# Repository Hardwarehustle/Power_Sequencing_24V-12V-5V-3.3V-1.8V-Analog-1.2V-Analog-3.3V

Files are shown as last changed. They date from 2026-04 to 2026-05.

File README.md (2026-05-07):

# Power Sequencing Design — Multi-Rail DC Power Distribution Board

## Project Overview

This project presents a **complete multi-rail power sequencing board** that converts **250V AC mains** down to a cascaded hierarchy of DC voltage rails — from 24V down to 1.2V — for powering mixed-signal embedded systems. The board supports **SoC/MCU cores, analog front-ends, relay/driver circuits**, and precision ADC/DAC references, all with controlled power-up sequencing via MCU GPIO enable pins.

The design covers:
- Full **schematic capture** in EasyEDA
- **PCB layout** with proper power and ground plane separation
- **Component selection** rationale with IC datasheets
- **MCU-controlled enable sequencing** via GPIO + P-MOSFET
- **Verification & Validation plan** (LTSpice simulation + physical testing)

---

## Project Visuals

### Schematic
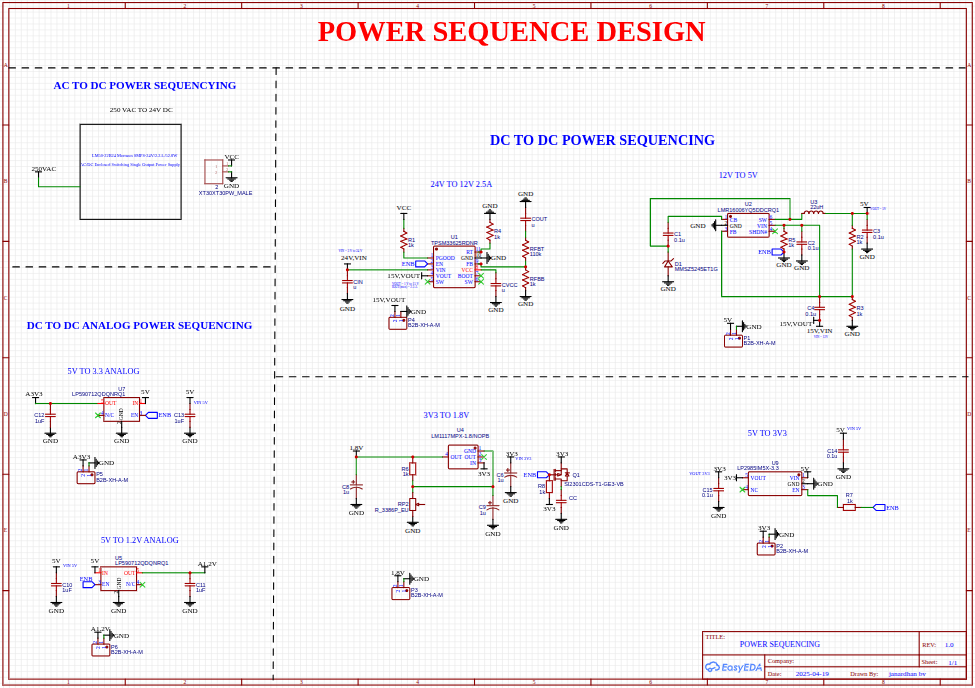
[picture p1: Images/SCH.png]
Schematic


### PCB Layout
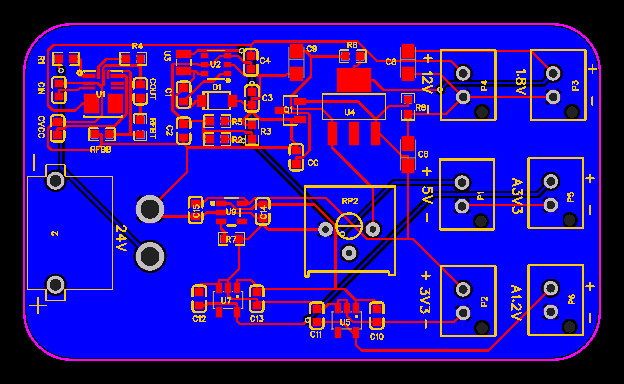
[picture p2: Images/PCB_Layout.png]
PCB Layout


### 3D Board Top View
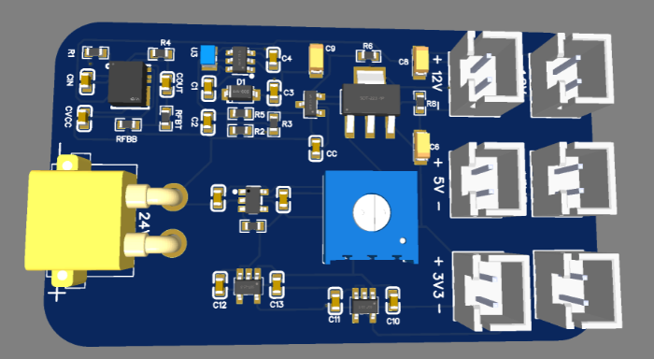
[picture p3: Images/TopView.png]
3D Top View


### 3D Board Bottom View
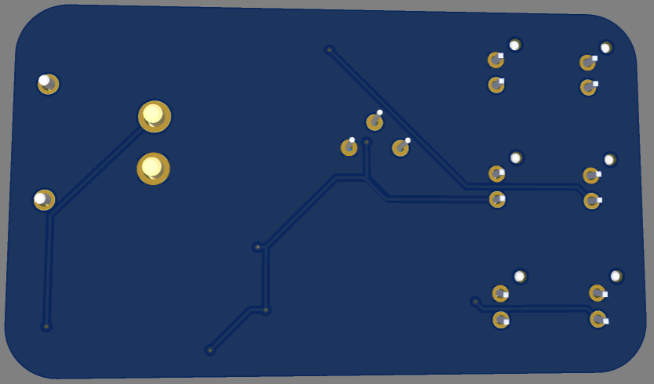
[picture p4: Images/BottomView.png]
3D Bottom View


---

## Power Architecture

The board implements a **top-down cascaded power tree**:

```
250V AC
   └─► 24V DC  (AC-DC SMPS — Mean Well LRS-35-24)
           ├─► 12V DC  (Buck Converter — LM2675-12)
           └─► 5V DC   (Buck Converter — LM7805 / LM2675-5.0)
                   ├─► 3.3V Digital   (LDO — TLV1117-33)
                   ├─► 1.8V Digital   (LDO — LM1117MPX-1.8)
                   ├─► Analog 1.2V    (Precision LDO — TPS7A02-1.2)
                   └─► Analog 3.3V    (Low-Noise LDO — TPS7A4700)
```

**Power-up sequence:**  
`24V → 12V → 5V → 3.3V → 1.8V → Analog 1.2V → Analog 3.3V`

---

## Load Requirements

| Voltage Rail | Load Current | Purpose |
|:---:|:---:|:---|
| 12V | 300 mA | Relay / Driver Circuits |
| 5V | 5 mA | MCU Supply, LDO Inputs |
| 3.3V (Digital) | 10 mA | MCU I/O, Comm. Interfaces |
| 1.8V | 100 mA | SoC / MCU Core Voltage |
| Analog 1.2V | 150 mA | ADC/DAC References |
| Analog 3.3V | 100 mA | Analog Sensors / Op-Amps |

---

## Component Selection

| Voltage Domain | Load | Type | IC | Why Selected |
|:---|:---:|:---:|:---|:---|
| 24V (AC-DC) | 2.2A | SMPS | Mean Well LRS-35-24 | Reliable, compact, 35W rated |
| 12V | 300 mA | Buck Reg | LM2675-12 | High-efficiency, 1A switch, 52 kHz, external EN |
| 5V | 5 mA | Buck Reg | LM7805 / LM2675-5.0 | Simple linear/buck for low current |
| 3.3V Digital | 10 mA | LDO | TLV1117-33 | Compact, stable, low dropout |
| 1.8V Digital | 100 mA | LDO | LM1117MPX-1.8 | Popular, stable for digital rails |
| Analog 1.2V | 150 mA | Low-Noise LDO | TPS7A02-1.2 | Ultralow noise, high PSRR, low IQ |
| Analog 3.3V | 100 mA | Low-Noise LDO | TPS7A4700 | Excellent PSRR, high-performance analog |

---

## Role of Each Power Domain

### 24V Rail
- Acts as the **intermediate supply** from AC mains via SMPS
- Feeds the first buck stage (12V converter)

### 12V Rail
- Supplies **high-current peripherals**: relays, solenoids, motor drivers
- Used in external interface circuits requiring higher voltage

### 5V Rail
- Functions as the **logic-level domain** and input to downstream LDO regulators
- Powers LEDs, simple logic blocks, and MCU supply

### 3.3V Digital Rail
- Supplies **MCU I/O**, communication interfaces (UART, I2C, SPI)
- Supports low-power digital peripherals

### 1.8V Digital Rail
- Used as **core supply** for MCUs, SoCs, and memory devices
- Essential for low-voltage digital logic

### Analog 1.2V Rail
- Provides a **low-noise reference voltage** for ADC/DAC references
- Powers RF circuits and sensitive analog sections

### Analog 3.3V Rail
- Delivers a **clean analog power rail** for Op-Amps and precision analog components
- Isolated from the digital 3.3V to prevent noise coupling

---

## MCU-Based Power Control

Power sequencing is controlled by an MCU via **GPIO-driven enable pins** on each regulator stage:

| Regulator / IC | Control Method |
|:---|:---|
| TPSM33625 | EN pin ← MCU GPIO |
| LMR16006 | SHDN# pin ← MCU GPIO |
| LP5907 (U5, U7) | EN pin ← MCU GPIO |
| LP2985 | EN pin ← MCU GPIO |
| LM1117MPX-1.8 | GPIO → Gate of P-MOSFET (SI2301) → LDO VIN |

> **Note:** A **P-MOSFET (Q1 - SI2301)** is used for the LM1117 stage. The MCU GPIO drives the gate, and a pull-up resistor (R8) ensures the rail defaults **OFF** on system reset — providing safe startup behavior.

---

## PCB Design Highlights

- **Tool:** EasyEDA (Schematic + Layout)
- **Layer stack:** 2-layer PCB (Red = Top copper, Blue = Bottom copper)
- **Connector interface:** JST B2B-XH-A-M style connectors for each output rail
- **24V input:** XT30 male power connector (high-current barrel/plug)
- **Output headers:** Labeled `+12V`, `+5V`, `+3V3`, `+1.8V`, `A3V3`, `A1.2V`
- **Decoupling caps:** Placed close to each IC for EMI suppression
- **Analog/Digital separation:** Analog LDO outputs (TPS7A02, TPS7A4700) routed separately from digital switching rails

---

## Verification & Validation Plan

### Phase 1 — LTSpice Simulation

| Simulation Type | Goal |
|:---|:---|
| DC Operating Point | Verify static output voltages at all rails |
| Transient Analysis | Observe power-up/down voltage waveforms |
| Load Transient | Test voltage stability under sudden load steps |
| Ripple & Noise | Measure peak-to-peak and RMS output ripple |
| Efficiency & Stability | Bode plots for phase margin and gain margin |

### Phase 2 — Physical Board Bring-Up

1. **Component Inspection** — Verify part numbers, orientation, polarity of capacitors/diodes
2. **Continuity Check** — Multimeter check on all power/ground nets
3. **No-Load Voltage Measurement** — Confirm all rails at correct voltages
4. **Load Regulation Test** — Apply rated loads (e.g., 300 mA at 12V) and verify regulation
5. **Power Sequencing Verification** — Oscilloscope capture of `24V → 12V → 5V → 3.3V → 1.8V → A1.2V → A3.3V`
6. **Thermal Check** — IR thermometer / thermal camera for hotspot detection
7. **EMI/EMC Screening** — Preliminary conducted/radiated emissions check

---

## Getting Started

### Prerequisites
- **EasyEDA** (free, browser-based EDA tool) or compatible Gerber viewer
- **LTSpice** for simulation verification
- **Multimeter + Oscilloscope** for physical validation

### Running the Design
1. Open the `.json` or `.sch` source files in EasyEDA
2. Review schematic for each power stage
3. Export Gerbers from the PCB editor for fabrication
4. Program MCU with GPIO sequencing firmware for controlled power-on

---

## License

This project is open for educational and personal use.  
© 2025 Janardhan BV — All rights reserved.

---

## Author

**Janardhan BV**  
Embedded Hardware Engineer | PCB Design | Power Electronics  
Bengaluru, India.

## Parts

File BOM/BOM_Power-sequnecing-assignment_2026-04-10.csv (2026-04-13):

ID | Name | Designator | Footprint | Quantity | Manufacturer Part | Manufacturer | Supplier | Supplier Part | Price | Pins | 3DModel | Contributor | JLCPCB Part Class | Value(Ω) | link
1 | 0.1u | C1,C2,C3,C4,C14,C15,CC | C0603 | 7 |  |  |  |  |  | 2 | C0603_L1.6-W0.8-H0.8 | LCEDA_Lib |  |  | https://item.szlcsc.com/362304.html
2 | 1uF | C10,C11,C12,C13 | C0603 | 4 |  |  |  |  |  | 2 | C0603_L1.6-W0.8-H0.8 | LCEDA_Lib |  |  | https://item.szlcsc.com/362304.html
3 | u | CIN,COUT,CVCC | C0603 | 3 |  |  |  |  |  | 2 | C0603_L1.6-W0.8-H0.8 | LCEDA_Lib |  |  | https://item.szlcsc.com/362304.html
4 | 1u | C6,C8,C9 | CASE-A_3216 | 3 |  |  |  |  |  | 2 | CASE-A_3216 | LCEDA_Lib |  |  | https://item.szlcsc.com/2057730.html
5 | MMSZ5245ET1G | D1 | SOD-123_L2.7-W1.6-LS3.7-RD | 1 | MMSZ5245ET1G | onsemi(安森美) | LCSC | C463089 | 0.633 | 2 | SOD-123_L2.7-W1.6-H1.4-LS3.7 | LCSC | Extended Part |  | https://item.szlcsc.com/13409.html
6 | SI2301CDS-T1-GE3-VB | Q1 | SOT-23-3_L2.9-W1.3-P1.90-LS2.4-BR | 1 | SI2301CDS-T1-GE3-VB | VBsemi(微碧半导体) | LCSC | C5438957 | 0.037 | 3 | SOT-23-3P_L2.9-W1.3-H1.0-LS2.4-P0.95 | lcsc | Extended Part |  | https://www.diodes.com/assets/Package-Files/SOT23.pdf
7 | 1k | R1,R2,R3,R4,R5,R6,R7,R8,RFBB | R0603 | 9 |  |  |  |  |  | 2 | R0603 | LCEDA_Lib |  |  | https://www.mouser.in/datasheet/2/447/PYu_RT_1_to_0_01_RoHS_L_11-1669912.pdf
8 | 110k | RFBT | R0603 | 1 |  |  |  |  |  | 2 | R0603 | LCEDA_Lib |  |  | https://www.mouser.in/datasheet/2/447/PYu_RT_1_to_0_01_RoHS_L_11-1669912.pdf
9 | R_3386P_EU | RP2 | RES-ADJ-TH_3386P | 1 |  |  | LCSC |  |  | 3 | RES-ADJ-TH_3386P | LCEDA_Lib |  | 10K | https://lcsc.com/product-detail/Precision-Potentiometer_Made-in-China-3386P-1-104_C5070.html
10 | TPSM33625RDNR | U1 | QFN-11_L4.5-W3.5-P0.50-TL_TPSM365R6FRDNR | 1 | TPSM33625RDNR | TI(德州仪器) | LCSC | C7073593 | 3.356 | 11 | QFN-11_L4.5-W3.5-P0.50-TL_TPSM365R6FRDNR | lcsc | Extended Part |  | https://www.ti.com/lit/ds/symlink/tpsm365r6.pdf
11 | LMR16006YQ5DDCRQ1 | U2 | TSOT-23-6_L2.9-W1.6-P0.95-LS2.8-BR | 1 | LMR16006YQ5DDCRQ1 | TI(德州仪器) | LCSC | C962072 | 2.486 | 6 | TSOT-23-6_L2.9-W1.6-H1.1-LS2.8-P0.95 | lcsc | Extended Part |  | https://item.szlcsc.com/117832.html
12 | 22uH | U3 | IND-SMD_L2.1-W1.5 | 1 | SNR.201610.SYB220MT00 | SOREDE(索瑞达) | LCSC | C5122815 | 0.048 | 2 | IND-SMD_L2.1-W1.5 | lcsc | Extended Part |  | https://atta.szlcsc.com/upload/public/pdf/source/20180321/3FD7197C8FC05ACDA75AA02A347602B7.pdf
13 | LM1117MPX-1.8/NOPB | U4 | SOT-223-4_L6.5-W3.5-P2.30-LS7.0-BR | 1 | LM1117MPX-1.8/NOPB | TI(德州仪器) | LCSC | C2877970 |  | 4 | SOT-223-4P_L6.5-W3.5-H1.6-LS7.0-P2.30 | LCSC | Extended Part |  | https://item.szlcsc.com/84517.html
14 | LP590712QDQNRQ1 | U5,U7 | SOT-23-5_L3.0-W1.7-P0.95-LS2.8-BR | 2 | LP5907MFX-1.8/NOPB | TI(德州仪器) | LCSC | C92498 | 0.163 | 5 | SOT-23-5_L2.9-W1.6-H1.1-LS2.8-P0.95 | lcsc | Extended Part |  | https://item.szlcsc.com/236104.html
15 | LP2985IM5X-3.3 | U9 | SOT-23-5_L2.9-W1.6-P0.95-LS2.8-BR | 1 | LP2985IM5X-3.3 | TECH PUBLIC(台舟) | LCSC | C5380655 | 0.166 | 5 | SOT-23-5_L2.9-W1.6-P0.95-LS2.8-BR | lcsc | Extended Part |  | https://atta.szlcsc.com/upload/public/pdf/source/20201015/C882654_F49EC15FD6A974BF40D8ED13350A683B.pdf
16 | XT30XT30PW_MALE | 2 | XT30PW_MALE | 1 |  |  |  |  |  | 4 | XT30-TH_XT30PW-M20.G.Y | akun pang
17 | B2B-XH-A-M | P1,P2,P3,P4,P5,P6 | CONN-TH_B2B-XH-A-M | 6 | B2B-XH-A-MB2P-VH（SMT业务专用） | JST | LCSC | C2683608 | 0.049 | 2 | CONN-TH_B2B-XH-A-M | LCSC | Extended Part |  | https://item.szlcsc.com/2780587.html

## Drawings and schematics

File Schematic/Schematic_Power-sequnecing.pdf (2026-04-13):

## 12V TO 5V

# AC TO DC POWER SEQUENCYING

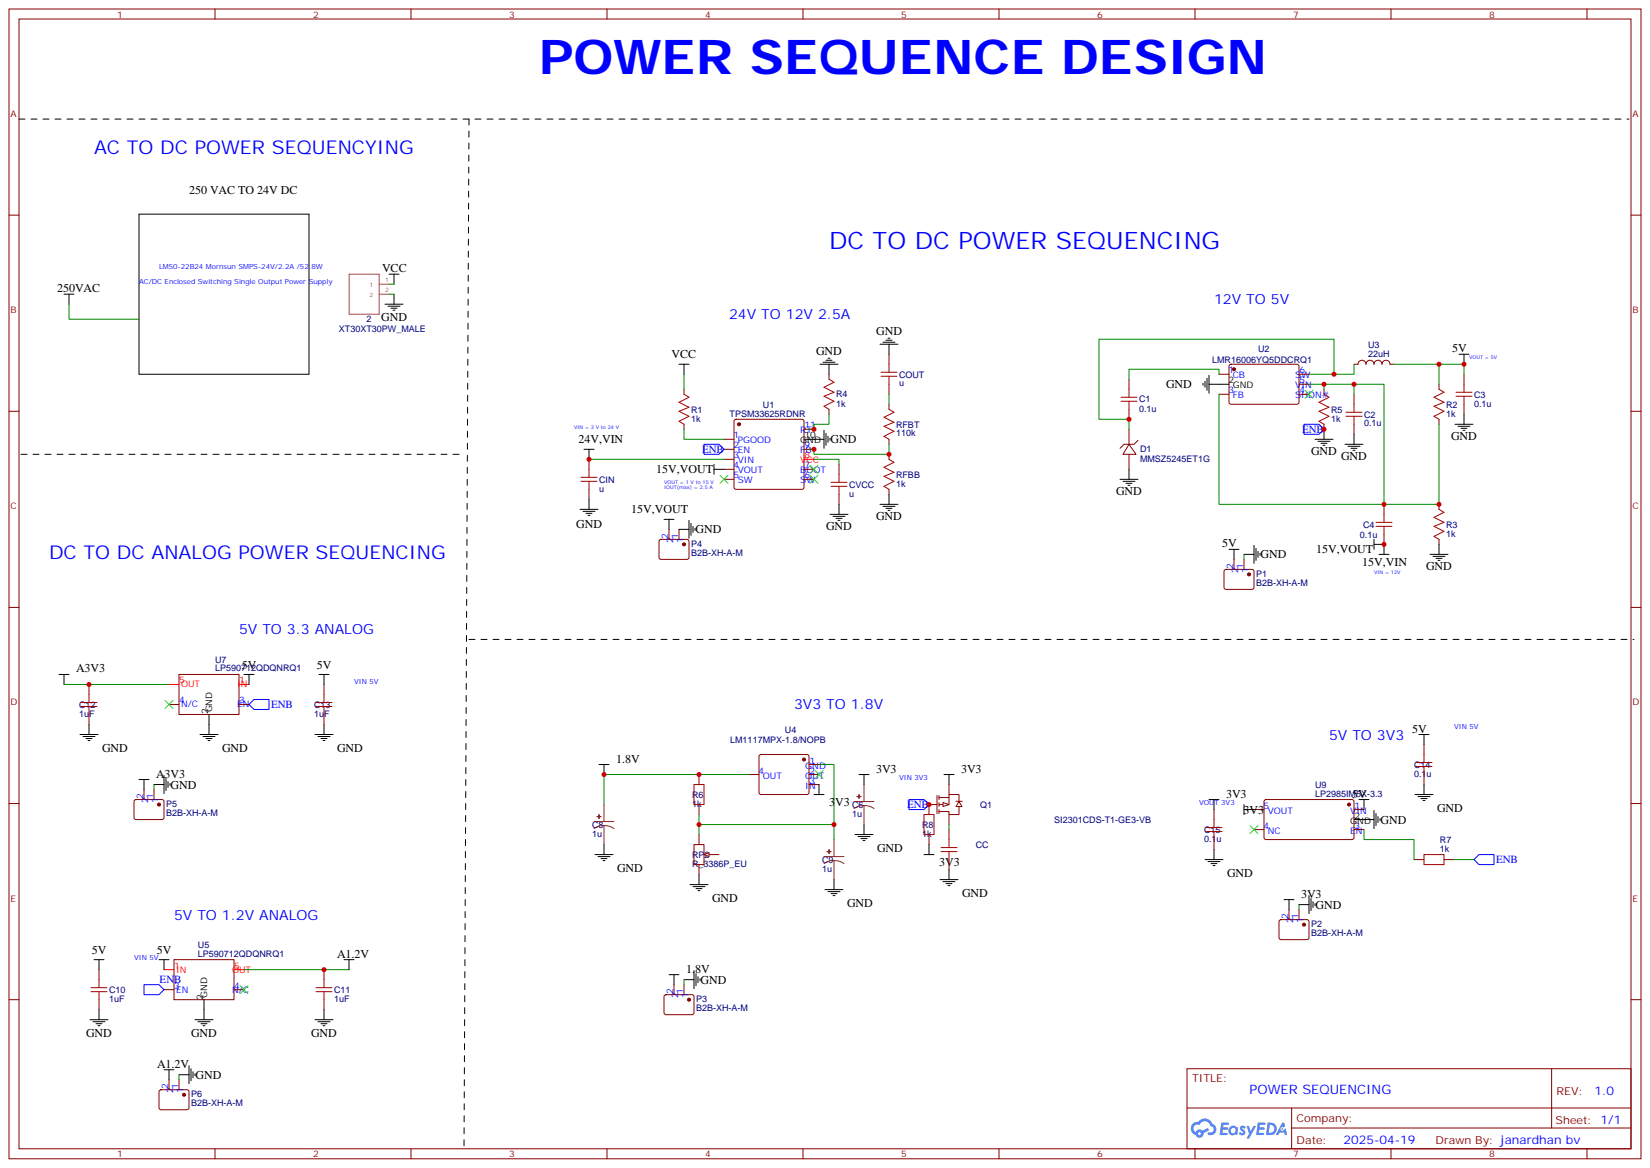
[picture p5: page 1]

DC TO DC POWER SEQUENCING

DC TO DC ANALOG POWER SEQUENCING

Drawn By: janardhan bv

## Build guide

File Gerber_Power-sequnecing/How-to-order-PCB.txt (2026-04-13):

How to Order PCB

Please refer to:
https://docs.easyeda.com/en/PCB/Order-PCB
